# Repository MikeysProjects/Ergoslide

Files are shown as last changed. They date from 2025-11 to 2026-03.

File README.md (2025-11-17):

# Ergoslide

## Repo layout

- .github
  - Workflows that build the firmware(s) for the microcontroller that runs the keyboard
- 3d files
  - The source Fusion 360 projects that produce the models for the case
- boards
  - The ZMK shield configuration
- config
  - Global ZMK shield configuration
- images
  - Images (e.g. PNGs, DXFs) needed to create the board or case
- models
  - Output models from Fusion 360 for the case
- pcb
  - The Kicad project for the keyboard PCB
- plates
  - Layouts exported from KLE, useful for creating either 3d models or DXFs for having the top plate manufactured, or automating the layout of the PCB
- zephyr
  - Root Zephyr config

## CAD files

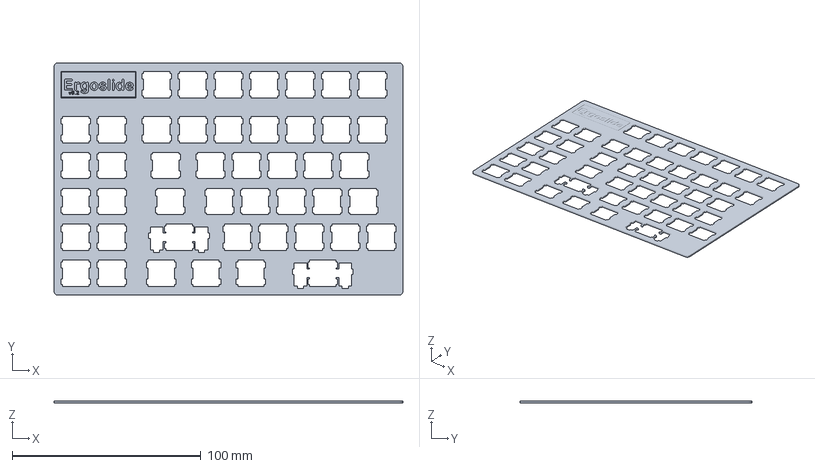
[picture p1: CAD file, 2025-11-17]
3d files/left-plate-test.3mf
185.0 x 123.1 x 1.20 mm

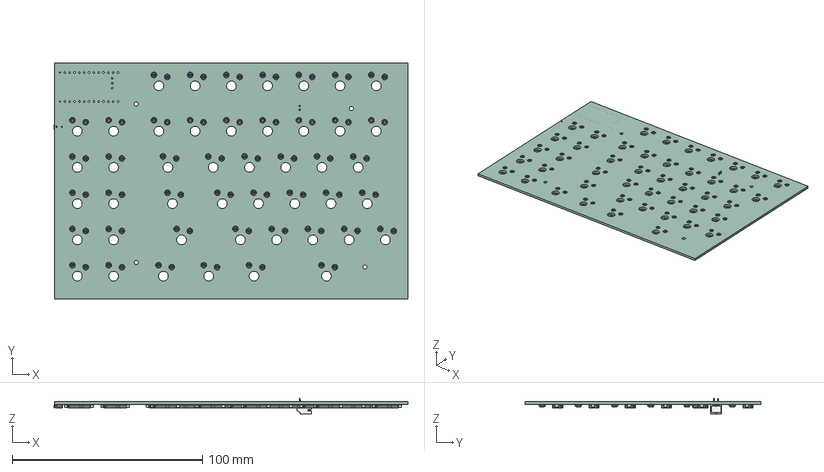
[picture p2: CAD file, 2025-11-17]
models/Ergoslide-Left-PCB.step
186.1 x 123.8 x 8.25 mm
Diode_SOD-123 x 46
Gateron-KS33-Socket x 46
JST_PH_S2B-PH-K_1x02_P2.00mm_Horizontal
Panasonic_EVQPUL_EVQPUC
Ergoslide_PCB

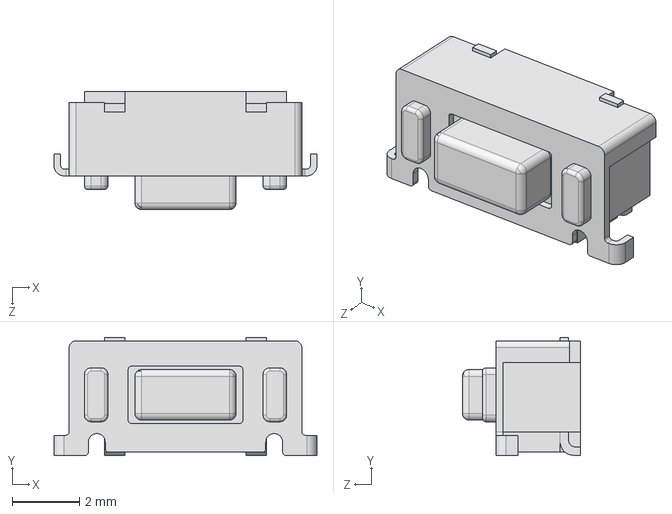
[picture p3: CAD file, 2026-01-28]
pcb/Ergoslide/additional libraries/TL3330AF260QG/TL3330AF260QG.step
7.80 x 3.50 x 3.51 mm

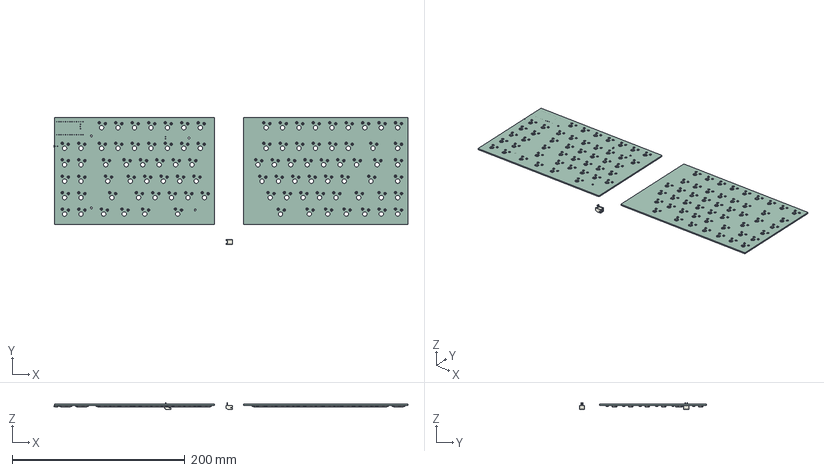
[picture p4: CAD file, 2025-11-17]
pcb/Ergoslide/Ergoslide.step
409.9 x 147.2 x 8.25 mm
Diode_SOD-123 x 95
Gateron-KS33-Socket x 95
JST_PH_S2B-PH-K_1x02_P2.00mm_Horizontal x 2
Panasonic_EVQPUL_EVQPUC
Ergoslide_PCB_1
Ergoslide_PCB_2

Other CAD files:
images/bottom plate pattern.dxf

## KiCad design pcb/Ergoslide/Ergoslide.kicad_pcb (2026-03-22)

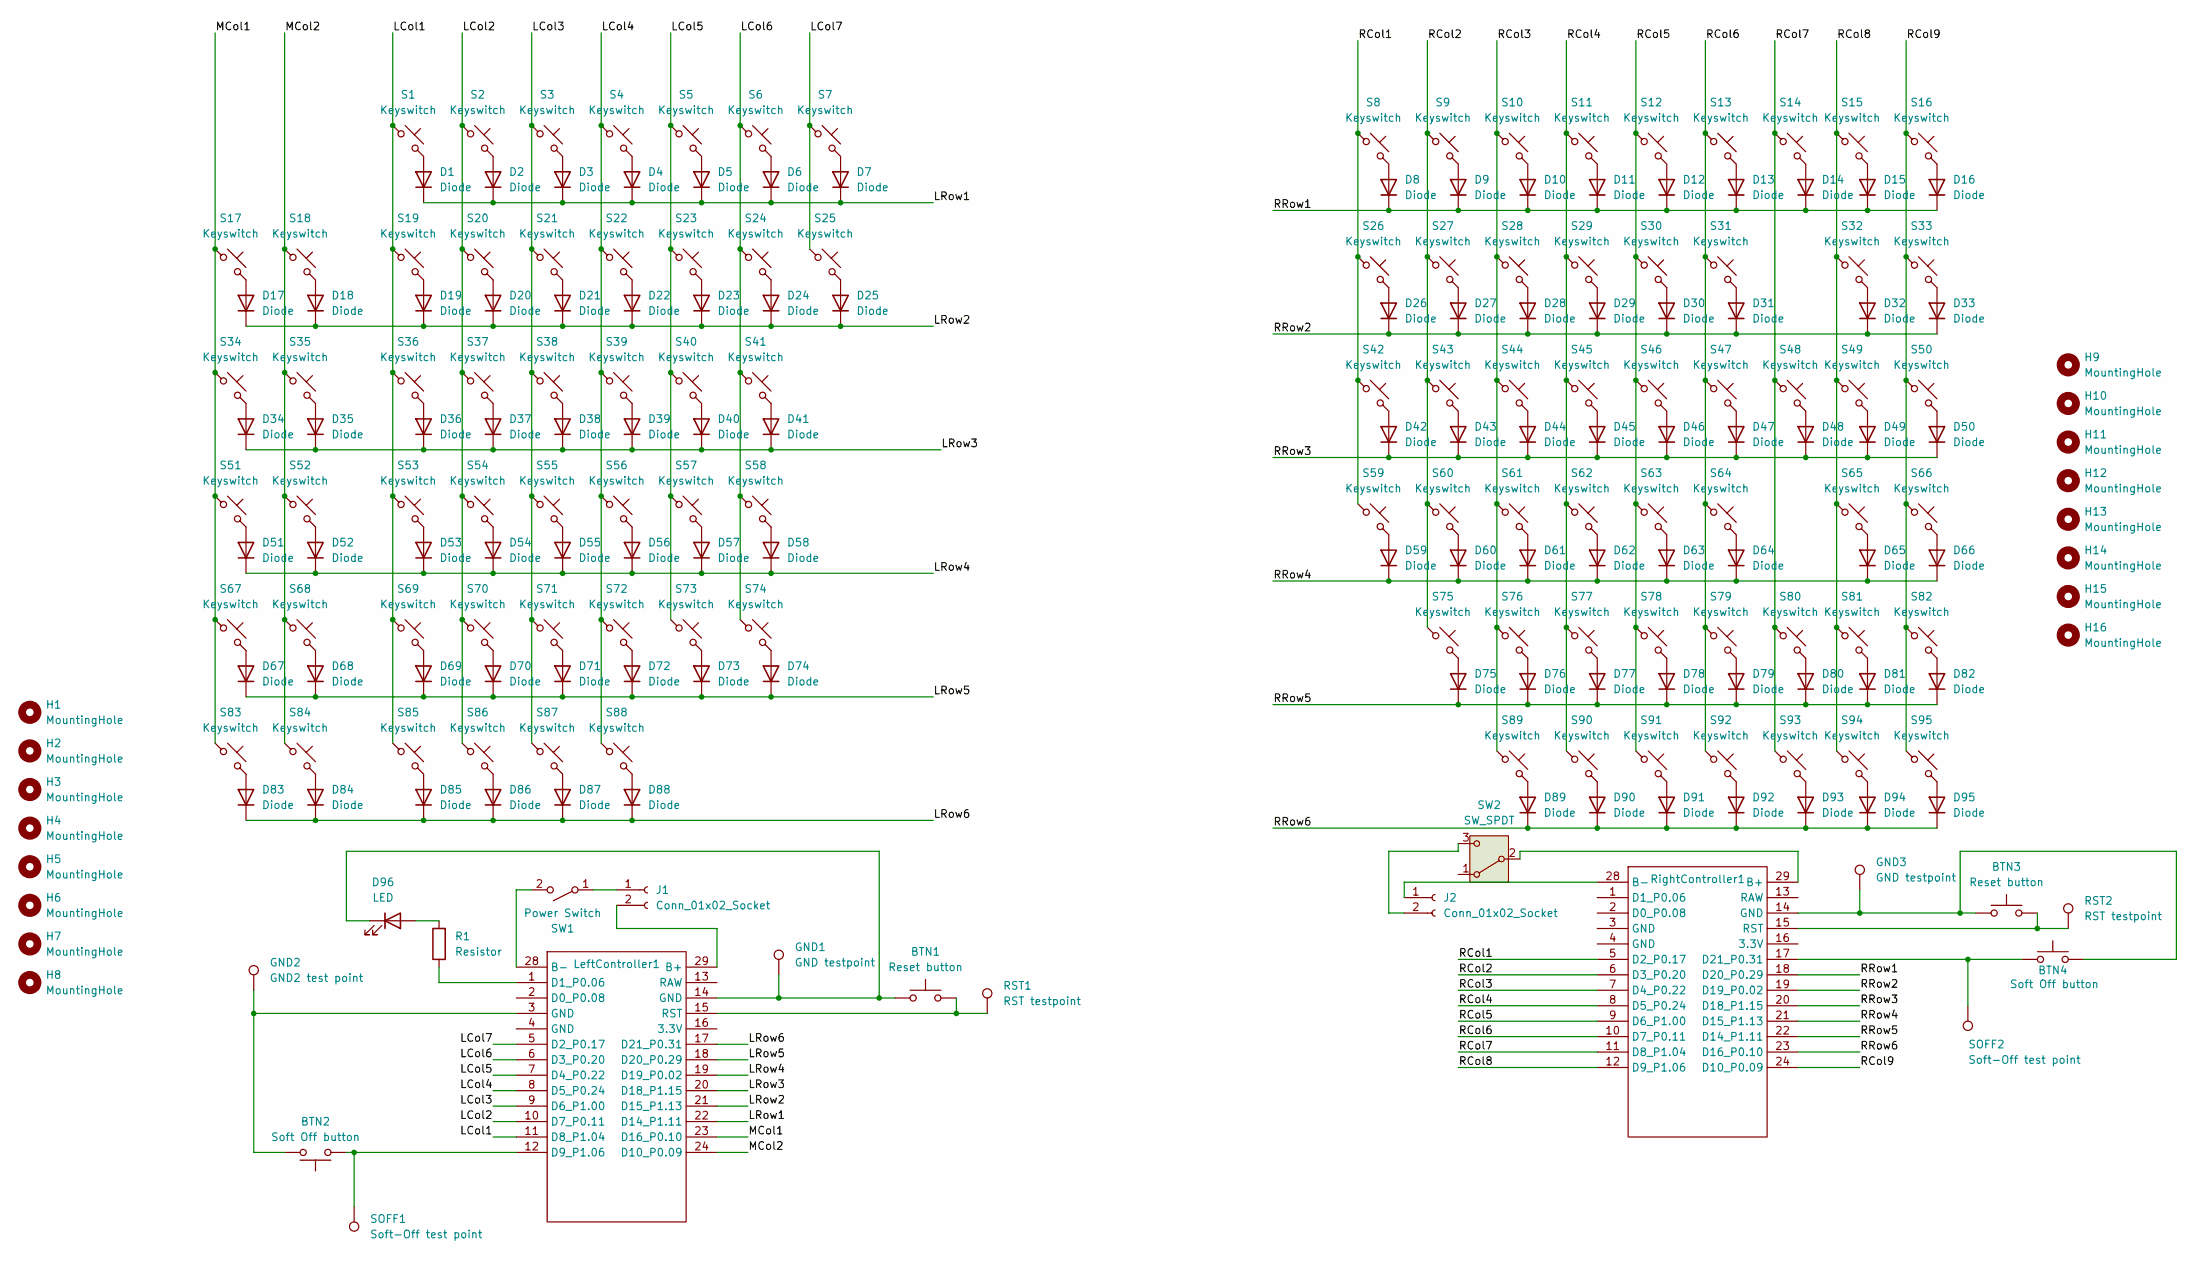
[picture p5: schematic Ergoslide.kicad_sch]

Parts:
BTN1, BTN3: Reset button; SW_TL3330AF260QG
BTN2, BTN4: Soft Off button; SW_TL3330AF260QG
D1, D2, D3, D4, D5, D6, D7, D8, D9, D10, D11, D12, D13, D14, D15, D16, D17, D18, D19, D20, D21, D22, D23, D24, D25, D26, D27, D28, D29, D30, D31, D32, D33, D34, D35, D36, D37, D38, D39, D40, D41, D42, D43, D44, D45, D46, D47, D48, D49, D50, D51, D52, D53, D54, D55, D56, D57, D58, D59, D60, D61, D62, D63, D64, D65, D66, D67, D68, D69, D70, D71, D72, D73, D74, D75, D76, D77, D78, D79, D80, D81, D82, D83, D84, D85, D86, D87, D88, D89, D90, D91, D92, D93, D94, D95: Diode; Diode_SOD-123
D96: LED; LED_0603_1608Metric
GND1, GND3: GND testpoint; TestPoint_Pad_2.0x2.0mm
GND2: GND2 test point; TestPoint_Pad_2.0x2.0mm
H1, H2, H3, H4, H5, H6, H7, H8, H9, H10, H11, H12, H13, H14, H15, H16: MountingHole; MountingHole_2.2mm_M2
J1, J2: Conn_01x02_Socket; JST_PH_S2B-PH-K_1x02_P2.00mm_Horizontal
LeftController1: SuperMini NRF52840
R1: Resistor; R_0603_1608Metric
RST1, RST2: RST testpoint; TestPoint_Pad_2.0x2.0mm
RightController1: SimpleMini NRF52840
S1, S2, S3, S4, S5, S6, S7, S8, S9, S10, S11, S12, S13, S14, S15, S16, S17, S18, S19, S20, S21, S22, S23, S24, S25, S26, S27, S28, S29, S30, S31, S33, S34, S35, S37, S38, S39, S40, S41, S42, S43, S44, S45, S46, S47, S48, S50, S51, S52, S54, S55, S56, S57, S58, S59, S60, S61, S62, S63, S64, S66, S67, S68, S70, S71, S72, S73, S74, S75, S76, S77, S78, S79, S81, S82, S83, S84, S91, S93, S94, S95: Keyswitch; Gateron-KS33-Hotswap-1U
S32: Keyswitch; Gateron-KS33-Hotswap-2U
S36, S49: Keyswitch; Gateron-KS33-Hotswap-1.5U
S53, S80: Keyswitch; Gateron-KS33-Hotswap-1.75U
S65, S69, S89: Keyswitch; Gateron-KS33-Hotswap-2.25U Stabilized
S85, S86, S87, S90, S92: Keyswitch; Gateron-KS33-Hotswap-1.25U
S88: Keyswitch; Gateron-KS33-Hotswap-2.75U Stabilized
SOFF1, SOFF2: Soft-Off test point; TestPoint_Pad_2.0x2.0mm
SW1: Power Switch; SW_SPDT_CK_JS102011SAQN
SW2: SW_SPDT; SW_SPDT_CK_JS102011SAQN

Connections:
/LCol1: LeftController1.11 (D8_P1.04), S1.1, S19.1, S36.1, S53.1, S69.1, S85.1
/LCol2: LeftController1.10 (D7_P0.11), S2.1, S20.1, S37.1, S54.1, S70.1, S86.1
/LCol3: LeftController1.9 (D6_P1.00), S3.1, S21.1, S38.1, S55.1, S71.1, S87.1
/LCol4: LeftController1.8 (D5_P0.24), S4.1, S22.1, S39.1, S56.1, S72.1, S88.1
/LCol5: LeftController1.7 (D4_P0.22), S5.1, S23.1, S40.1, S57.1, S73.1
/LCol6: LeftController1.6 (D3_P0.20), S6.1, S24.1, S41.1, S58.1, S74.1
/LCol7: LeftController1.5 (D2_P0.17), S7.1, S25.1
/LRow1: D1.1 (K), D2.1 (K), D3.1 (K), D4.1 (K), D5.1 (K), D6.1 (K), D7.1 (K), LeftController1.22 (D14_P1.11)
/LRow2: D17.1 (K), D18.1 (K), D19.1 (K), D20.1 (K), D21.1 (K), D22.1 (K), D23.1 (K), D24.1 (K), D25.1 (K), LeftController1.21 (D15_P1.13)
/LRow3: D34.1 (K), D35.1 (K), D36.1 (K), D37.1 (K), D38.1 (K), D39.1 (K), D40.1 (K), D41.1 (K), LeftController1.20 (D18_P1.15)
/LRow4: D51.1 (K), D52.1 (K), D53.1 (K), D54.1 (K), D55.1 (K), D56.1 (K), D57.1 (K), D58.1 (K), LeftController1.19 (D19_P0.02)
/LRow5: D67.1 (K), D68.1 (K), D69.1 (K), D70.1 (K), D71.1 (K), D72.1 (K), D73.1 (K), D74.1 (K), LeftController1.18 (D20_P0.29)
/LRow6: D83.1 (K), D84.1 (K), D85.1 (K), D86.1 (K), D87.1 (K), D88.1 (K), LeftController1.17 (D21_P0.31)
/MCol1: LeftController1.23 (D16_P0.10), S17.1, S34.1, S51.1, S67.1, S83.1
/MCol2: LeftController1.24 (D10_P0.09), S18.1, S35.1, S52.1, S68.1, S84.1
/RCol1: RightController1.5 (D2_P0.17), S8.1, S26.1, S42.1, S59.1
/RCol2: RightController1.6 (D3_P0.20), S9.1, S27.1, S43.1, S60.1, S75.1
/RCol3: RightController1.7 (D4_P0.22), S10.1, S28.1, S44.1, S61.1, S76.1, S89.1
/RCol4: RightController1.8 (D5_P0.24), S11.1, S29.1, S45.1, S62.1, S77.1, S90.1
/RCol5: RightController1.9 (D6_P1.00), S12.1, S30.1, S46.1, S63.1, S78.1, S91.1
/RCol6: RightController1.10 (D7_P0.11), S13.1, S31.1, S47.1, S64.1, S79.1, S92.1
/RCol7: RightController1.11 (D8_P1.04), S14.1, S48.1, S80.1, S93.1
/RCol8: RightController1.12 (D9_P1.06), S15.1, S32.1, S49.1, S65.1, S81.1, S94.1
/RCol9: RightController1.24 (D10_P0.09), S16.1, S33.1, S50.1, S66.1, S82.1, S95.1
/RRow1: D8.1 (K), D9.1 (K), D10.1 (K), D11.1 (K), D12.1 (K), D13.1 (K), D14.1 (K), D15.1 (K), D16.1 (K), RightController1.18 (D20_P0.29)
/RRow2: D26.1 (K), D27.1 (K), D28.1 (K), D29.1 (K), D30.1 (K), D31.1 (K), D32.1 (K), D33.1 (K), RightController1.19 (D19_P0.02)
/RRow3: D42.1 (K), D43.1 (K), D44.1 (K), D45.1 (K), D46.1 (K), D47.1 (K), D48.1 (K), D49.1 (K), D50.1 (K), RightController1.20 (D18_P1.15)
/RRow4: D59.1 (K), D60.1 (K), D61.1 (K), D62.1 (K), D63.1 (K), D64.1 (K), D65.1 (K), D66.1 (K), RightController1.21 (D15_P1.13)
/RRow5: D75.1 (K), D76.1 (K), D77.1 (K), D78.1 (K), D79.1 (K), D80.1 (K), D81.1 (K), D82.1 (K), RightController1.22 (D14_P1.11)
/RRow6: D89.1 (K), D90.1 (K), D91.1 (K), D92.1 (K), D93.1 (K), D94.1 (K), D95.1 (K), RightController1.23 (D16_P0.10)
unnamed: BTN2.2, GND2.1, LeftController1.3 (GND)
unnamed: BTN3.1, BTN4.2, GND3.1, RightController1.14 (GND)
unnamed: D1.2 (A), S1.2
unnamed: D2.2 (A), S2.2
unnamed: D3.2 (A), S3.2
unnamed: D4.2 (A), S4.2
unnamed: D5.2 (A), S5.2
unnamed: D6.2 (A), S6.2
unnamed: D7.2 (A), S7.2
unnamed: D8.2 (A), S8.2
unnamed: D9.2 (A), S9.2
unnamed: D10.2 (A), S10.2
unnamed: D11.2 (A), S11.2
unnamed: D12.2 (A), S12.2
unnamed: D13.2 (A), S13.2
unnamed: D14.2 (A), S14.2
unnamed: D15.2 (A), S15.2
unnamed: D16.2 (A), S16.2
unnamed: D17.2 (A), S17.2
unnamed: D18.2 (A), S18.2
unnamed: D19.2 (A), S19.2
unnamed: D20.2 (A), S20.2
unnamed: D21.2 (A), S21.2
unnamed: D22.2 (A), S22.2
unnamed: D23.2 (A), S23.2
unnamed: D24.2 (A), S24.2
unnamed: D25.2 (A), S25.2
unnamed: D26.2 (A), S26.2
unnamed: D27.2 (A), S27.2
unnamed: D28.2 (A), S28.2
unnamed: D29.2 (A), S29.2
unnamed: D30.2 (A), S30.2
unnamed: D31.2 (A), S31.2
unnamed: D32.2 (A), S32.2
unnamed: D33.2 (A), S33.2
unnamed: D34.2 (A), S34.2
unnamed: D35.2 (A), S35.2
unnamed: D36.2 (A), S36.2
unnamed: D37.2 (A), S37.2
unnamed: D38.2 (A), S38.2
unnamed: D39.2 (A), S39.2
unnamed: D40.2 (A), S40.2
unnamed: D41.2 (A), S41.2
unnamed: D42.2 (A), S42.2
unnamed: D43.2 (A), S43.2
unnamed: D44.2 (A), S44.2
unnamed: D45.2 (A), S45.2
unnamed: D46.2 (A), S46.2
unnamed: D47.2 (A), S47.2
unnamed: D48.2 (A), S48.2
unnamed: D49.2 (A), S49.2
unnamed: D50.2 (A), S50.2
unnamed: D51.2 (A), S51.2
unnamed: D52.2 (A), S52.2
unnamed: D53.2 (A), S53.2
unnamed: D54.2 (A), S54.2
unnamed: D55.2 (A), S55.2
unnamed: D56.2 (A), S56.2
unnamed: D57.2 (A), S57.2
unnamed: D58.2 (A), S58.2
unnamed: D59.2 (A), S59.2
unnamed: D60.2 (A), S60.2
unnamed: D61.2 (A), S61.2
unnamed: D62.2 (A), S62.2
unnamed: D63.2 (A), S63.2
unnamed: D64.2 (A), S64.2
unnamed: D65.2 (A), S65.2
unnamed: D66.2 (A), S66.2
unnamed: D67.2 (A), S67.2
unnamed: D68.2 (A), S68.2
unnamed: D69.2 (A), S69.2
unnamed: D70.2 (A), S70.2
unnamed: D71.2 (A), S71.2
unnamed: D72.2 (A), S72.2
unnamed: D73.2 (A), S73.2
unnamed: D74.2 (A), S74.2
unnamed: D75.2 (A), S75.2
unnamed: D76.2 (A), S76.2
unnamed: D77.2 (A), S77.2
unnamed: D78.2 (A), S78.2
unnamed: D79.2 (A), S79.2
unnamed: D80.2 (A), S80.2
unnamed: D81.2 (A), S81.2
unnamed: D82.2 (A), S82.2
unnamed: D83.2 (A), S83.2
unnamed: D84.2 (A), S84.2
unnamed: D85.2 (A), S85.2
unnamed: D86.2 (A), S86.2
unnamed: D87.2 (A), S87.2
unnamed: D88.2 (A), S88.2
unnamed: D89.2 (A), S89.2
unnamed: D90.2 (A), S90.2
unnamed: D91.2 (A), S91.2
unnamed: D92.2 (A), S92.2
unnamed: D93.2 (A), S93.2
unnamed: D94.2 (A), S94.2
unnamed: D95.2 (A), S95.2
unnamed: D96.2 (A), R1.2
unnamed: BTN1.1, D96.1 (K), GND1.1, LeftController1.14 (GND)
unnamed: J1.1, SW1.1 (A)
unnamed: J1.2, LeftController1.29 (B+)
unnamed: J2.1, RightController1.28 (B-)
unnamed: J2.2, SW2.3 (C)
unnamed: LeftController1.28 (B-), SW1.2 (B)
unnamed: LeftController1.1 (D1_P0.06), R1.1
unnamed: BTN2.1, LeftController1.12 (D9_P1.06), SOFF1.1
unnamed: BTN1.2, LeftController1.15 (RST), RST1.1
unnamed: RightController1.29 (B+), SW2.2 (B)
unnamed: BTN4.1, RightController1.17 (D21_P0.31), SOFF2.1
unnamed: BTN3.2, RST2.1, RightController1.15 (RST)

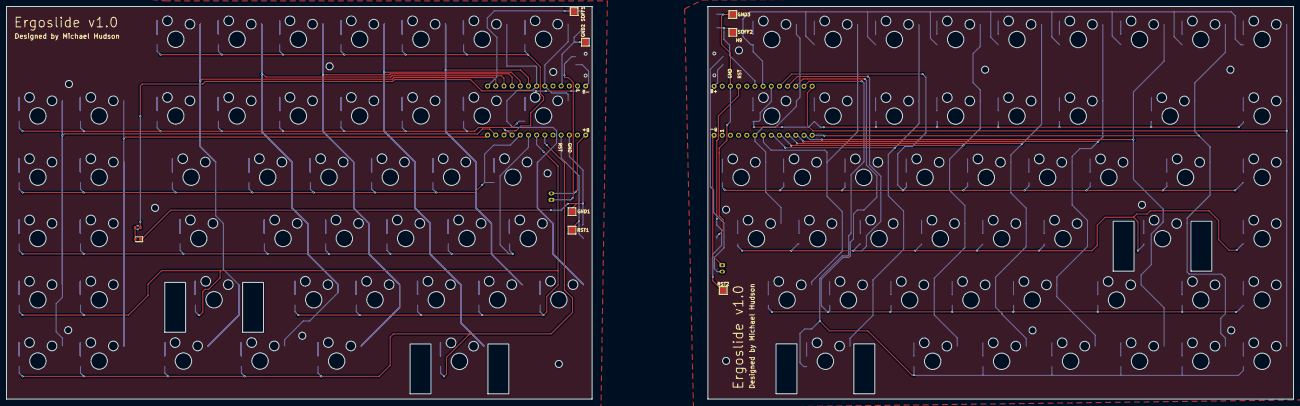
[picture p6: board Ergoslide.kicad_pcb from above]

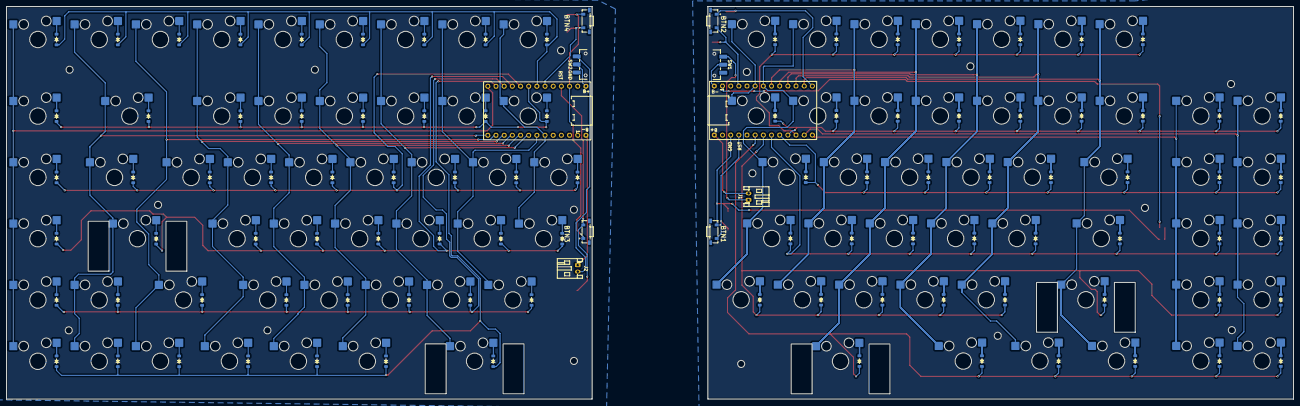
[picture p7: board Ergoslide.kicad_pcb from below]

Board: 2 copper layers, 400.0 x 122.0 mm, 225 parts (200 on the bottom side), 140 nets.

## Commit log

2025-08-24 Add plate layout
2025-08-24 Update the layout of the Ergoslide to have macro keys on the left hand side
    [Ergoslide.kicad_pcb, Ergoslide.kicad_sch]
2025-08-24 Update the spacing on the left and right sides of the board
    This will make the left and right halves exactly the same
    width in terms of the keys used
2025-08-24 Fix bad rename for plates
2025-08-24 Start wiring up the PCB
    [Ergoslide.kicad_pcb, Ergoslide.kicad_sch]
2025-08-24 Fully route the matrix
    [Ergoslide.kicad_pcb]
2025-08-24 Muck about with custom footprints and symbols for the Supermini
    Started wiring the Supermini in to the left side matrix
    [Ergoslide.kicad_pcb, Ergoslide.kicad_sch]
2025-08-24 Set up the board for PCB testing
2025-08-24 Move a printable key to the top-left slot
2025-08-24 Add row definitions to the right half of the board
2025-08-24 Switch some pins around
2025-08-24 Clean up pcb directory in Git
    [Ergoslide.kicad_pcb, Ergoslide.kicad_sch]
2025-08-24 Switch the top two rows around
2025-08-24 Add the USB UART and ZMK Studio flag to the build config
2025-08-24 Add ZMK Studio unlock button
2025-11-17 Add the bottom pattern image for the case, as well as the Fusion project and exported STEP file
    [Ergoslide-Left-PCB.step, Ergoslide.kicad_sch, Ergoslide.step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]
2025-11-17 Add external power and don't allow anything to wake up the board
2025-11-18 Ignore some more temp files from Kicad
2026-01-28 Add TL3330AF260GQ to the PCB, start wiring up the second half
    [Ergoslide.kicad_pcb, Ergoslide.kicad_sch, TL3330AF260QG.step]
2026-02-19 Finish wiring up right hand side PCB
    [Ergoslide.kicad_pcb]
2026-02-19 Add fill zones
    [Ergoslide.kicad_pcb]
2026-03-07 Use stabilized switch cutouts
    [Ergoslide.kicad_pcb, Ergoslide.kicad_sch]
2026-03-07 Update ZMK build target for board revisions
2026-03-07 Use ZMK board variant in build matrix
2026-03-07 Add Caps Lock indicator LED support
2026-03-07 Disable UART0 to free D1 for Caps Lock LED
2026-03-07 Move nice!nano UART override to board overlay
2026-03-07 Use P1.01 for Caps Lock LED testing
2026-03-07 Use onboard LED for Caps Lock testing
2026-03-07 Force D1 Caps Lock LED on at boot
2026-03-07 Add compile check for caps lock LED source
2026-03-07 Build Caps Lock LED source into ZMK app target
2026-03-07 Enable GPIO LED driver for Caps Lock LED
2026-03-08 Add Caps Lock LED, remove labels for holes, realign labels for everything else
    [Ergoslide.kicad_pcb, Ergoslide.kicad_sch]
2026-03-08 Add some tacky text saying who made this thing
    [Ergoslide.kicad_pcb]
2026-03-19 Some small update to the PCB
2026-03-21 Restructure the keymap to match the matrix in Kicad
